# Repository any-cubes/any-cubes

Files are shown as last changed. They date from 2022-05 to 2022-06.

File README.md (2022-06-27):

# Any-Cubes

_Didactic toy for machine teaching and IoT_  

teaser (https://vimeo.com/488949042)

Any-Cubes is a prototype didactic toy for schools and maker spaces, with which children can intuitively and playfully explore and understand machine learning as well as Internet of Things technology. Our prototype is a combination of deep learning-based image classification and machine-to-machine (m2m) communication via [MQTT](https://mqtt.org/). The system consists of three physical and tangible cubes.

Cube 1 («[Vision-Cube](cubes/vision-cube/README.md)») is a modification of [Google Coral’s Teachable Machine](https://coral.ai/projects/teachable-machine/) and can be trained to recognize objects or scenes.
The machine learning functionality is running directly on the Raspberry Pi board, accelerated using a Google Edge TPU Stick.

Via the MQTT protocol, the Vision-Cube broadcasts its detected class ("1", "2" or "3") to other Any-Cubes devices ("Light-Cube" and "Maker-Cube").

Cube 2 («[Light-Cube](cubes/light-cube/README.md)») visualises the detected class of the Vision-Cube by changing the color of its LEDs.

Cube 3 («[Maker-Cube](cubes/maker-cube/README.md)») can be used to control other circuits using relays. It can for example be used to open an electronic cat door, whenever the Vision-Cube detects a cat.

It addition to the physical cubes, apps using web-technologies can be created easily to react to the changes of the Vision-Cube.
One such app is «[Shapes](apps/shapes-app/README.md)» – it shows different graphical shapes to visualise the classes being detected by the Vision-Cube. It can be used as a boilerplate to create custom apps that react to the Vision-Cube.

# Publications
 
Scheidt, A., & Pulver, T. (2019). Any-Cubes: A Children’s Toy for Learning AI: Enhanced Play with Deep Learning and MQTT. Proceedings of Mensch Und Computer 2019. [https://doi.org/10.1145/3340764.3345375](doi.org/10.1145/3340764.3345375)

# Contributors

Any-Cubes is a project by [Alexander Scheidt](https://www.fh-potsdam.de/studium-lehre/projekte/any-cubes) and [Tim Pulver](https://timpulver.de/) with contributions by [Meliani Meliani](https://www.linkedin.com/in/meliani-meliani-7a856b1a4/?originalSubdomain=de) (research and organisation of workshops), [Lukas Schmidt Wiegand](https://www.linkedin.com/in/lukas-schmidt-wiegand-67b990172/) (industrial design) and [Sabina Fimbres Sabugal](https://www.linkedin.com/in/sabina-fimbres-sabugal-7a253a213/) (graphic design for posters).

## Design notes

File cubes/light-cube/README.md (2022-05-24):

# Light-Cube

any-cubes-in-row

The Light-Cube (in the image above on the right) is part of the Any-Cubes family and can be used to visualise what the Vision-Cube (another cube from the Any-Cubes family) detects.

It listens to a special MQTT message from the Vision-Cube.

## Why Is This Useful?

The Light-Cube can be used in two ways:

1. As a helper to train the Vision-Cube – it shows which class the Vision-Cube currently sees and therefore makes training easier
2. As an alarm device – you can set up the Vision-Cube in one room, and the Light-Cube in another. When the Vision-Cube sees something that you trained it on, the light of the Light-Cube will change accordingly.

## Folder Contents

- [3D](3d/README.md): 3D-printable files to print the Light-Cube case, connection-rims and base plate
- [Code](code/README.md): The Arduino code
- [Wiring](wiring/README.md): Explains how to connect the electronic parts

## Required Electronic Parts

- **Arduino Nano 33 IoT**
  - [docs.arduino.cc/hardware/nano-33-iot](https://docs.arduino.cc/hardware/nano-33-iot)
- **LED Matrix**
  - [Adafruit NeoPixel Matrix 8x8](https://www.adafruit.com/product/1487) (or compatible LED matrix)
- **Logic Level Converter**
  - [SN74AHCT125N](https://eu.mouser.com/ProductDetail/Texas-Instruments/SN74AHCT125N?qs=1wQRf3HkBjyxwrHMwAiMfw%3D%3D) – we recommend this one, as most normal logic level converters don’t work well with NeoPixels
- **USB Powerbank**
  - Only needed if you want to carry the Light-Cube around
  - Make sure it delivers enough Ampere
  - We use Ansmann USB Powerbank 5.4: 5V, 2.4 Ampera max: https://www.ansmann.de/consumer/powerbanks/powerbank-54
  - Some powerbanks have a *clever* automation to automatically power off when the connected device is disconnected. With microcontroller-boards this can result in the power bank shutting off randomly, even when the board is still connected (because it might draw only very little power). The powerbank we are using didn’t do that, but some others that we tried did.
- **USB cable**
  - Make sure to use a quality cable, especially super thin ones might not work

## Getting Started

1. Connect the board and LED matrix as described in [wiring](wiring/README.md)
2. Train the Vision-Cube
3. The Light-Cube will update its color according to the detected class of the Vision-Cube

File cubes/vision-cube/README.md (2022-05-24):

# Vision-Cube

Vision-Cube being used to recognize a giraffe

The Vision-Cube uses machine learning to recognize different objects and scenes (in the image above, to recognize a giraffe). It can be trained using just a few images.
The Vison-Cube is based on [Google Coral’s Project Teachable](https://coral.ai/projects/teachable-machine/).

## Hardware

- Raspberry Pi 3 B+
- Google Coral USB Accelerator
- 5V USB Powerbank (with 2.5A or more)
- Four buttons (three for classification, one to reset the model)

## Software

We use a modified version of the [Google Coral’s Teachable Machine](https://github.com/google-coral/project-teachable) project.

Our modifications include:

- Installed an MQTT server ([mosquitto](https://mosquitto.org/)) to the Raspberry Pi
- Added auto-start of the detection script, so it starts automatically when the Raspberry Pi starts (see [Sparkfun – How to Run a Raspberry Pi Program on Startup](https://learn.sparkfun.com/tutorials/how-to-run-a-raspberry-pi-program-on-startup/all))

We might provide an SD-card image of the Vision-Cube on request that contains all modifications.

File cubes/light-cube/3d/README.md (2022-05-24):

# Light-Cube 3D Files

You can choose between different formats:

- Fusion 360
- OBJ
- STEP
- STL (contains some exclusive parts)

If you choose Fusion 360, OBJ or STEP, please also have a look at the STL folder. It might contain some parts than are not included in the other folders.

The base-plate is a work-in-progress and contains some holes, which are planned to be used in a later version of the Light-Cube (for example to contain a power-on/off switch and a USB charging port). Feel free to create your own base plate that fits to the base cube without these holes.

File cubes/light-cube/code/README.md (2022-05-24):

# Light-Cube Code

Here you can find the Arduino code for the Light-Cube.

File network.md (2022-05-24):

# Network

Any-Cubes modules need two things to communicate:

1. A network that it can connect to
2. An MQTT server (runs on the Vision-Cube)

## Local Usage

Any-Cubes currently only communicate locally, they don’t depend on an internet connection being available.

If you have a spare router, you can use it for the Any-Cubes network. This way it is easy to take Any-Cubes to a new location and start them up, without the need to re-configure their WiFi settings.

With an Any-Cubes specific router, the workflow would be like this:

1. Plug in the router. Wait a minute until it is ready.
2. Power up the Vision-Cube. Wait a minute until it is booted up and the MQTT server is ready.
3. Power up the remaining cubes

Using a separate network / router for the Any-Cubes is more secure, because all communication is separate to your regular WiFi network. Everything stays local, so there is no chance that your devices are exposed to the internet (which would require further work to secure the devices).

If you want to use any of the Any-Cubes apps on a tablet device you also need to do the following:

1. Connect the tablet to the same network the Any-Cubes are connected to
2. Serve the `index.html` file of the app, for example using the app [Kiosk Pro](https://www.kioskgroup.com/pages/kiosk-pro-software)

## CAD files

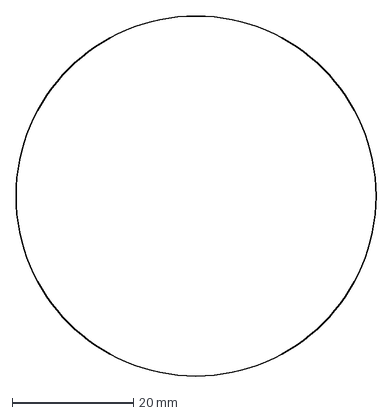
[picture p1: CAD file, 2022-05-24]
cubes/light-cube/3d/DXF-diffusor-for-laser-cutting/diffusor.dxf
59.5 x 59.5 mm

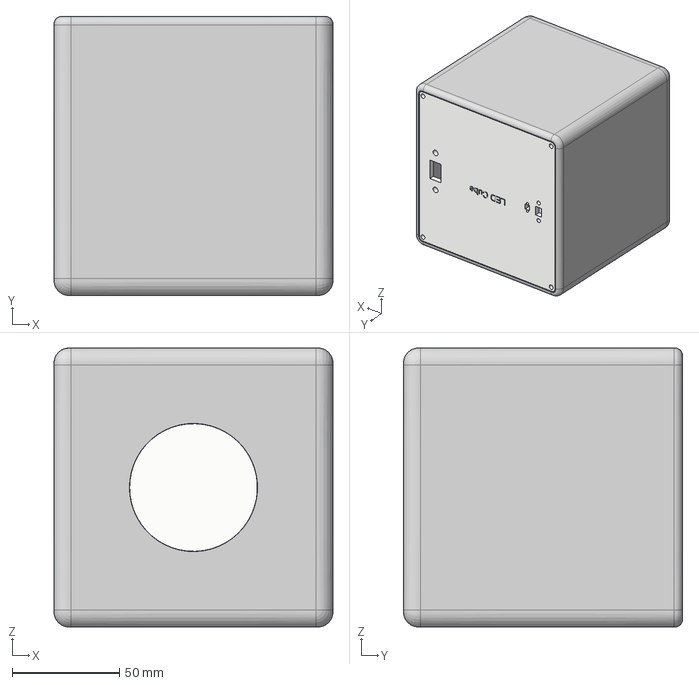
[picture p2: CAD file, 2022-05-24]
cubes/light-cube/3d/step/light-cube.step
130.0 x 130.0 x 130.0 mm

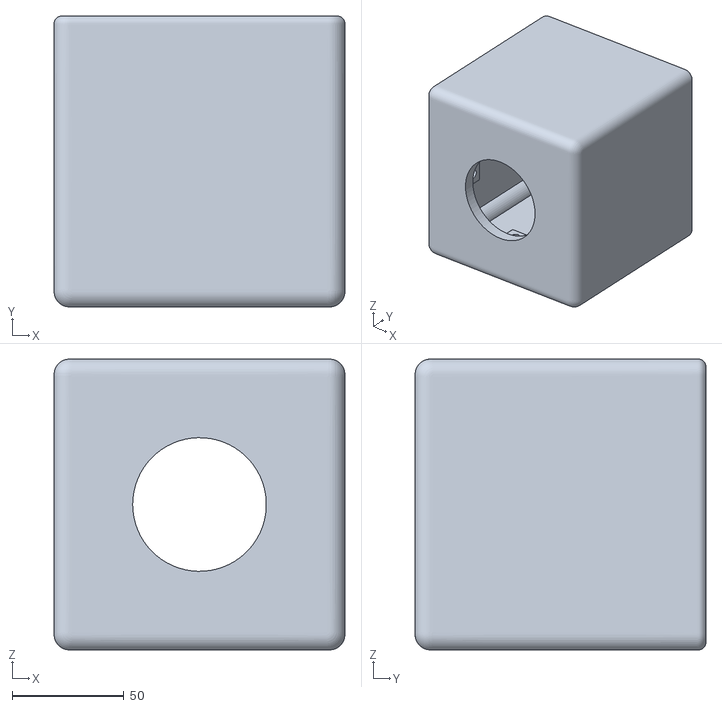
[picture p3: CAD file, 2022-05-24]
cubes/light-cube/3d/stl/light-cube-cube.stl
130.0 x 130.0 x 130.0

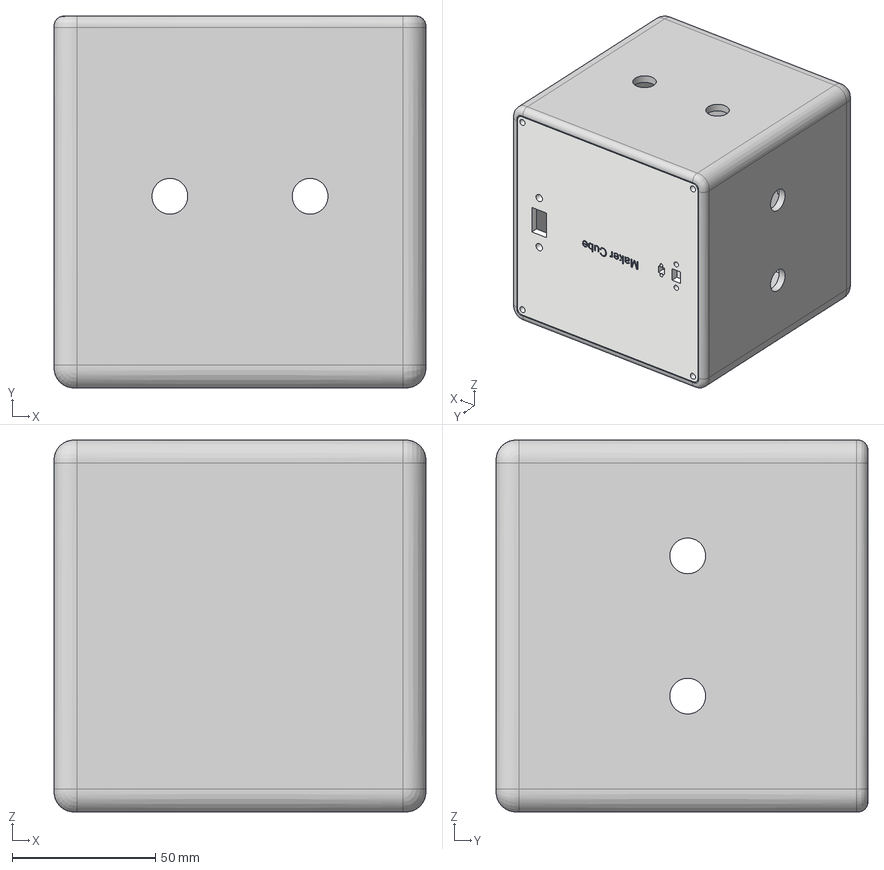
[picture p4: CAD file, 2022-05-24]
cubes/maker-cube/3d/step/maker-cube.step
130.0 x 130.0 x 130.0 mm

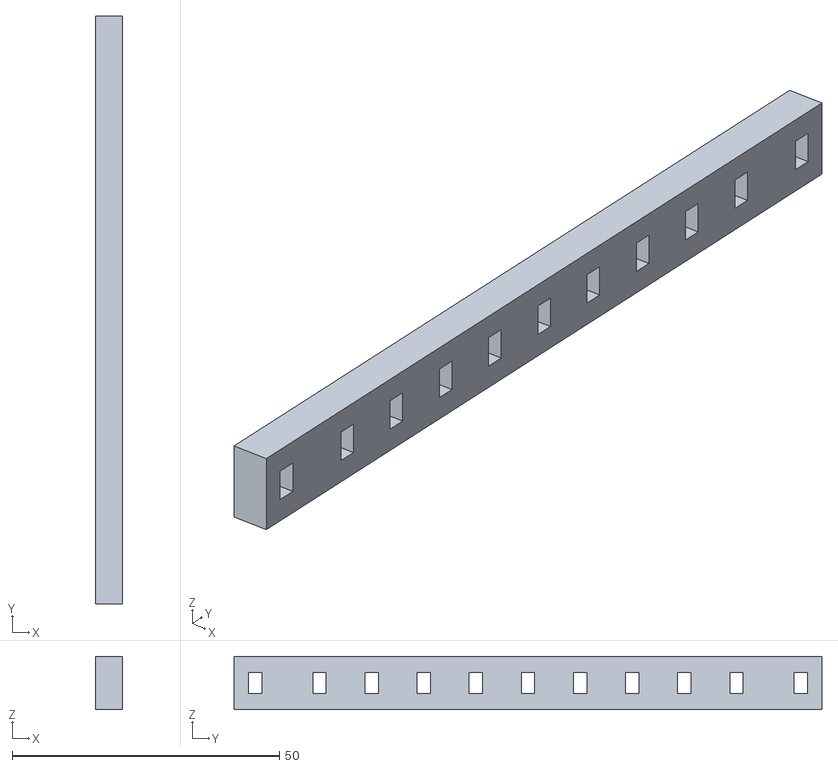
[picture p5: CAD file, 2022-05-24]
cubes/maker-cube/3d/stl/maker-cube-truss-bridge-vertical.stl
5.00 x 110.0 x 10.0

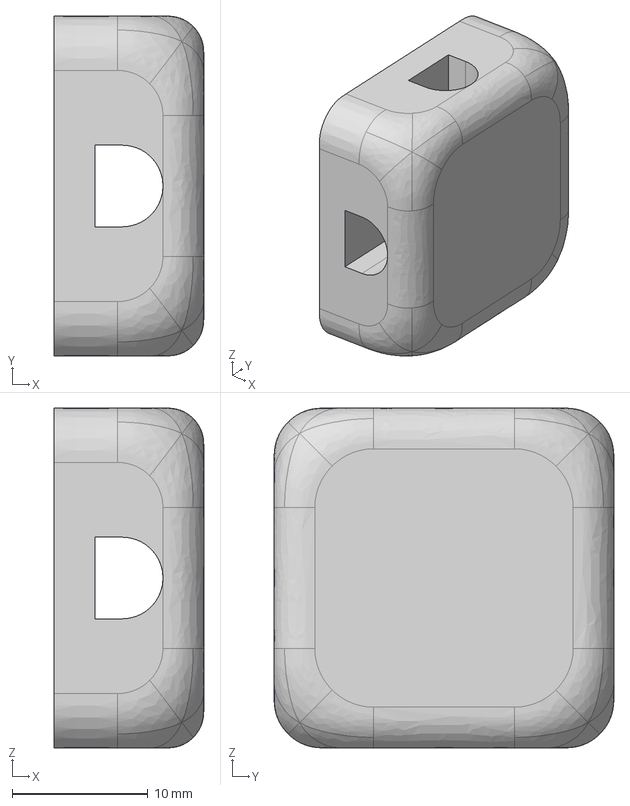
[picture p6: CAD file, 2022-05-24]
cubes/light-cube/3d/step/light-cube-mounting-pad.step
11.0 x 25.0 x 25.0 mm

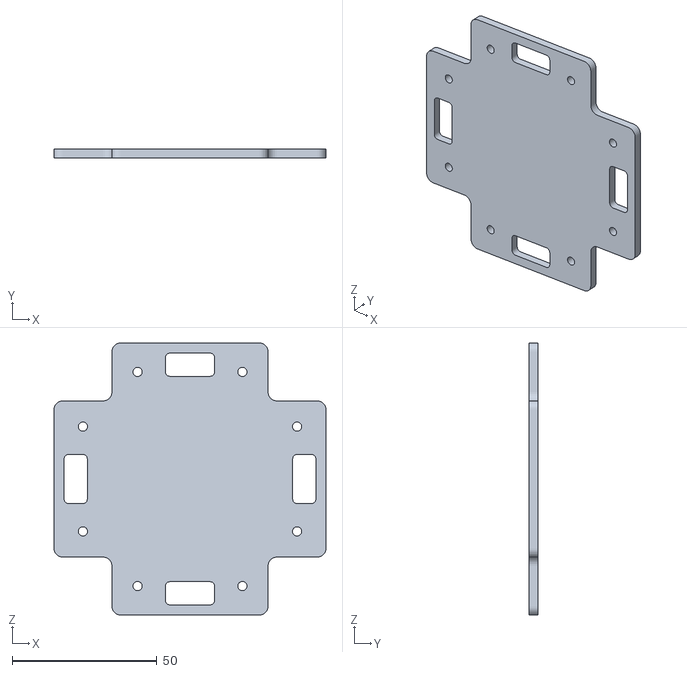
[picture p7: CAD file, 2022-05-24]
cubes/light-cube/3d/stl/light-cube-led-holder.stl
94.0 x 3.00 x 94.0

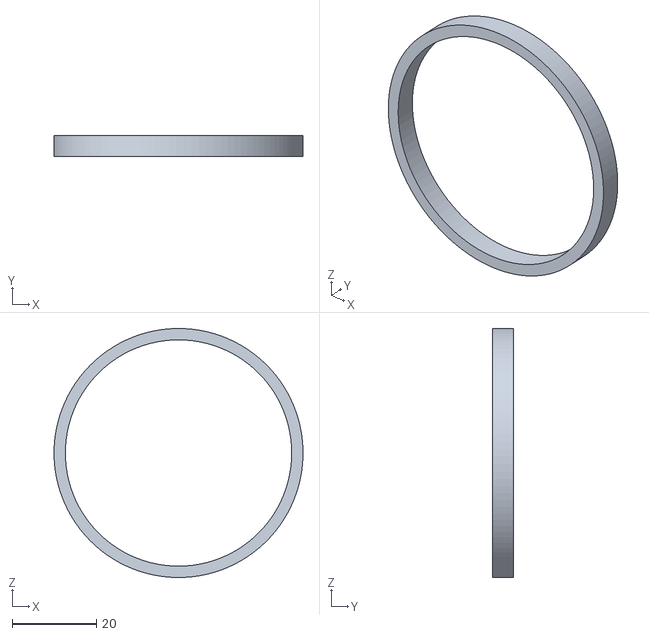
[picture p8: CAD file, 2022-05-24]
cubes/light-cube/3d/stl/light-cube-ring.stl
59.1 x 5.00 x 59.1

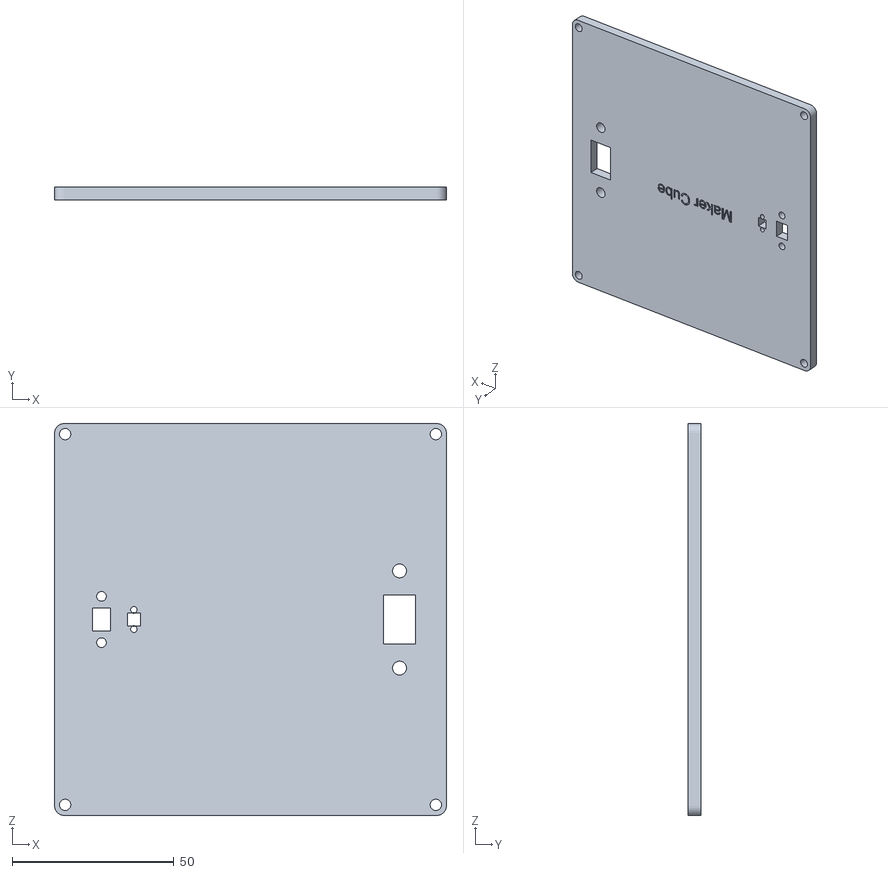
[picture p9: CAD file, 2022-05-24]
cubes/maker-cube/3d/stl/maker-cube-ground-plate.stl
121.0 x 4.00 x 121.0

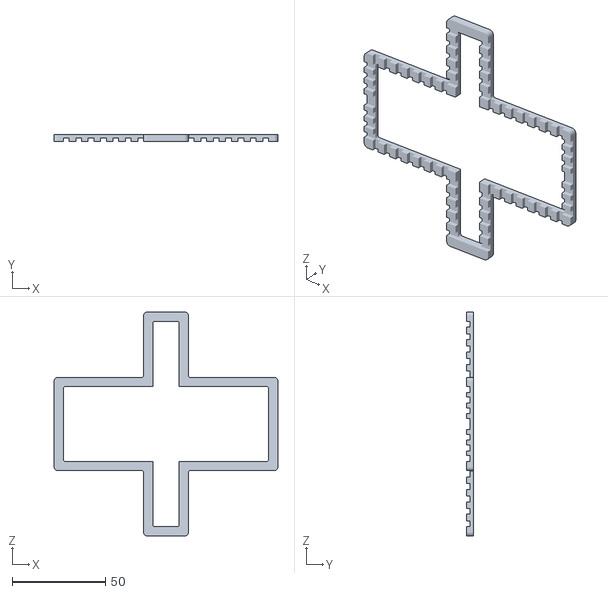
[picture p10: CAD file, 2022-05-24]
cubes/maker-cube/3d/stl/maker-cube-truss-cross-top.stl
120.0 x 4.00 x 120.0

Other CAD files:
cubes/maker-cube/3d/stl/maker-cube-cube.stl
cubes/light-cube/3d/stl/light-cube-ground-plate.stl
cubes/maker-cube/3d/stl/maker-cube-truss-cross-bottom.stl
cubes/light-cube/3d/fusion360/light-cube-mounting-Pad.f3d
cubes/light-cube/3d/fusion360/light-cube.f3d
cubes/light-cube/3d/stl/light-cube-mounting-pad.stl
cubes/maker-cube/3d/fusion360/maker-cube-mounting-pad.f3d
cubes/maker-cube/3d/fusion360/maker-cube.f3d
cubes/maker-cube/3d/stl/maker-cube-mounting-pad.stl

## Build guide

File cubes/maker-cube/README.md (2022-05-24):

# Maker-Cube

Maker-Cube with Vision Cube and Cow

The Maker-Cube is part of the Any-Cubes family and can be used to turn up to four external circuits on or off. Internally it uses relays, which either open or close another connected circuit. In the image above, it is being used to turn on a windmill toy whenever the Vision-Cube detects a cow.

It listens to a special MQTT message from the Vision-Cube (another cube from the Any-Cubes family that uses a camera and machine learning to recognise different scenes, so called «classes»).

## Why Is This Useful?

Let’s say you trained the Vison-Cube to recognise your cat and you also built a custom cat door that can electronically be opened or closed. You could use the Maker-Cube to connect the two projects, so whenever the Vision-Cube detects the cat, the cat door automatically opens.

## Folder Contents

In this repository you will find the following sub-folders:

- [3D](3d/README.md): 3D-printable files to print the Maker-Cube case, connection-rims and base plate
- [Code](code/README.md): The Arduino code
- [Wiring](wiring/README.md): Explains how to connect the electronic parts

## How Can a Circuit Be Connected to the Maker-Cube?

The Maker-Cube can be used to control any other (low-power) circuit, for example one of your Arduino projects or an electronic toy running on batteries, with minimal modifications.

To connect the Maker-Cube to other circuits, banana cables are being used.

**Attention:** While connecting high power circuits (e.g. a coffee machine) to the Maker-Cube might work, we do not recommend it, because it is very dangerous. Only use the Maker-Cube to control low-power devices / circuits, for example battery-driven projects.

To control another circuit using the Maker-Cube, you need to cut its power line. For an Arduino project this might be its VCC / 3.3V / 5V line.

One side of the cable then goes into one of the two ports of a Maker-Cube’s side, the other side of the cable goes into the other port. Whenever this side of the Maker-Cube is activated (via the Vision-Cube), the connection between the two ports is closed, and therefore the circuit of the connected project is closed as well.

**Please note:** The connected circuit must have its own power source. The Maker-Cube simply closes the circuit, but it does not provide power.

## Required Electronic Parts

- **NodeMCU V2**
  - We use a similar version to this one: https://joy-it.net/de/products/SBC-NodeMCU
- **Logic Level Converter**
  - We use 4-channel I2C-safe Bi-directional Logic Level Converter - BSS138: https://www.adafruit.com/product/757
- **Relais**
  - We use a Velleman 4x Relay VMA400: https://www.velleman.eu/products/view/?id=435558
  - Other relays might or might not work with a 3.3V development board. We tried a few other ones that only worked with 5V development boards.
- **Banana jacks / connector cables**
  - There are a multitude of banana jacks / connector cables. The most important thing is that the plug fits to the connector
  - For example: https://uk.farnell.com/hirschmann-testmeasurement/972354102/socket-4mm-safety-blue-mvl-s/dp/1011403
  - Search for «banana jack surface mount» to find others
  - For the Vision-Cube you need 2 jacks for each side, so 8 in total
  - You need one (long) banana cable per project that you want to connect
- **USB Powerbank**
  - Only needed if you want to carry the Maker-Cube around
  - Make sure it delivers enough Ampere
  - We use Ansmann USB Powerbank 5.4: 5V, 2.4 Ampera max: https://www.ansmann.de/consumer/powerbanks/powerbank-54
  - Some powerbanks have a *clever* automation to automatically power off when the connected device is disconnected. With microcontroller-boards this can result in the power bank shutting off randomly, even when the board is still connected (because it might draw only very little power). The powerbank we are using didn’t do that, but some others that we tried did.
- **USB cable**
  - Make sure to use a quality cable, especially super thin ones might not work

## Getting Started

1. Connect the board, relay and banana jacks as described in [wiring](wiring/README.md)

2. Cut the banana cable in half

3. Solder on one end of the banana cable to the end of the cable that opens the circuit of your other project
4. Do the same with the other half / side of the cable

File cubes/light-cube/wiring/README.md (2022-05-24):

# Light-Cube Wiring

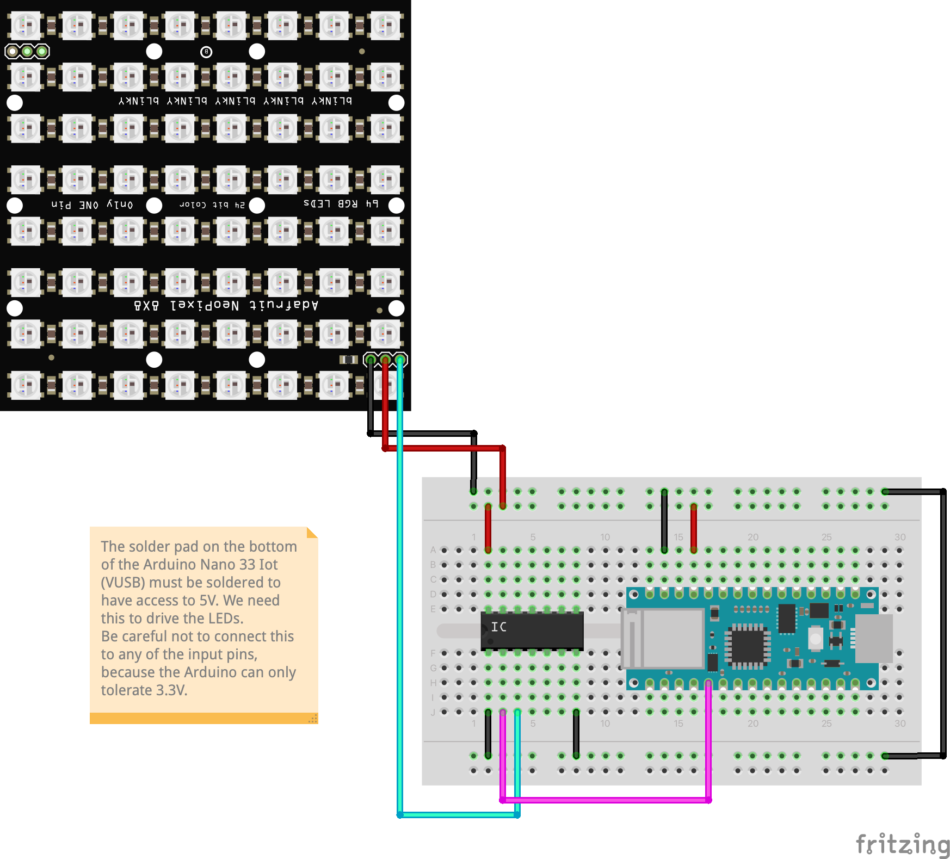
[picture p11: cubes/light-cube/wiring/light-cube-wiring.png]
Light-Cube Wiring


## Fritzing Installation

If looking at the wiring image (light-cube-wiring.png) is not enough and you want too view / edit the Fritzing file, you need to follow a few steps first:

1. Install [Fritzing](https://fritzing.org/)
2. Download the part *Adafruit NeoPixel NeoMatrix 8x8.fzpz* from [GitHub](https://github.com/adafruit/Fritzing-Library/blob/master/parts/Adafruit%20NeoPixel%20NeoMatrix%208x8.fzpz)
3. Downlod the part *NodeMCU v1.0* from [GitHub](https://github.com/squix78/esp8266-fritzing-parts/blob/master/nodemcu-v1.0/NodeMCUV1.0.fzpz)
4. Double click both files to open them in Fritzing
5. Open the Light-Cube Fritzing file

Please note: There is no Fritzing part for the *SN74AHCT125N logic level converter*, we just use an IC here with the same number of pins. The orientation of the part is so that its text can be read.

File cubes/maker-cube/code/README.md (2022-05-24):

# Maker-Cube Code

Here you can find the Arduino code for the Maker-Cube.

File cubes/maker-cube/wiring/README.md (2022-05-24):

# Maker-Cube Wiring

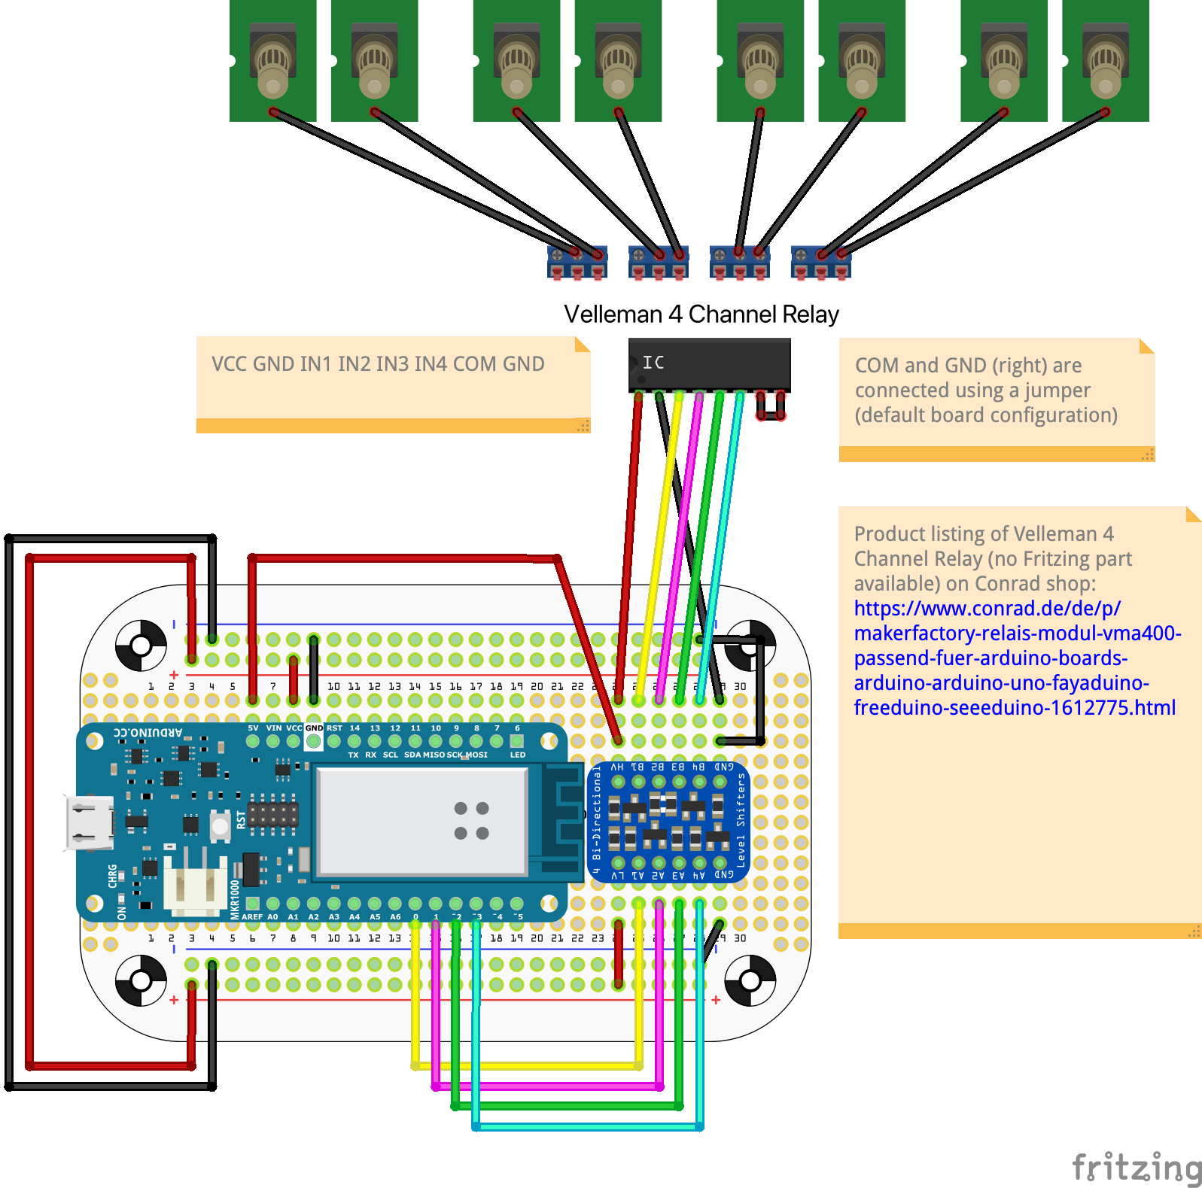
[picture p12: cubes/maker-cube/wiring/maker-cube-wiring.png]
Maker-Cube Wiring


## Fritzing Diagram

To view / edit the Fritzing file (for better resolution), you need to perform a few steps first:

1. Install [Fritzing](https://fritzing.org/)
2. Download the part *Adafruit PermaProto Mint Tin Size Breadboard* from [GitHub](https://github.com/adafruit/Fritzing-Library/blob/master/parts/Adafruit%20PermaProto%20Mint%20Tin%20Size%20Breadboard.fzpz)
3. Double click it to open it in Fritzing
4. Open the Maker-Cube Fritzing file

## Velleman VMA400 Board

The design does not contain the used relay board ([Velleman VMA400](https://www.velleman.eu/products/view/?id=435558)), but the Fritzing file uses the same port layout as this board, so you will be able to translate the design 1 to 1 to the board.

The IC symbolizes the Velleman VMA400 ports to the Arduino, the top part shows how to connect the outputs of the Velleman VMA400 board to the banana jacks.

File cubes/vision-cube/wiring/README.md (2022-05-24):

# Vision-Cube Wiring

To control the Vision-Cube, four buttons (including resistors) need to be connected to the Raspberry Pi.

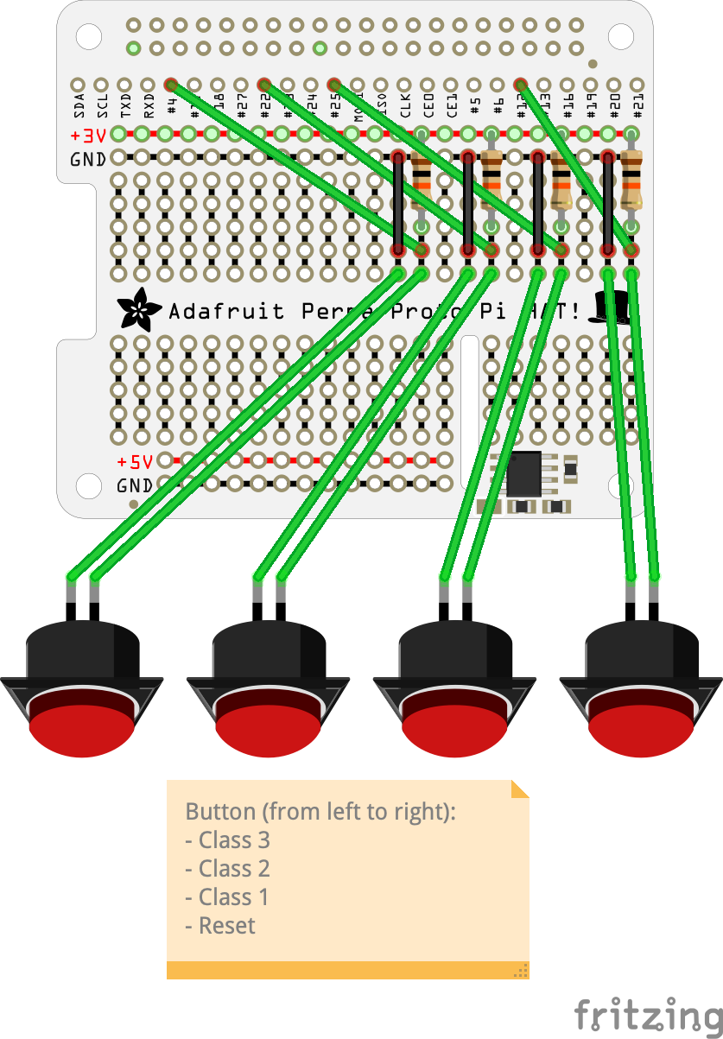
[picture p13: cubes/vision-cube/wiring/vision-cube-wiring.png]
Vision-Cube Wiring


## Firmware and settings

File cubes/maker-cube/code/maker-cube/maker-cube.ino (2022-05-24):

/*
 * Firmware for Any-Cubes Maker-Cube
 * ---------------------------------
 * The Maker-Cube is an output device from the Any-Cubes family.
 * Via its relays, it can be used to control up to four external (low-power) circuits
 * by switching the relays on or off individually.
 * It listens to control signals via MQTT from the Vision-Cube.
 * 
 * Author: The Any-Cubes authors
 * License: MIT
 * 
 * Hardware:
 * - NodeMCU V2:
 *     - We use a similar version to this one: https://joy-it.net/de/products/SBC-NodeMCU
 * - 4x Logic Level Converter:
 *     - We use a 4-channel I2C-safe Bi-directional Logic Level Converter - BSS138: https://www.adafruit.com/product/757
 * - 4x Relay
 *     - We use a Velleman VMA400: https://www.velleman.eu/products/view/?id=435558
 * - USB Powerbank:
 *     - Make sure it delivers enough Ampere
 *     - We use Ansmann USB Powerbank 5.4: 5V, 2.4 Ampera max: https://www.ansmann.de/consumer/powerbanks/powerbank-54
 * 
 * Libraries:
 * - PubSubClient (install via Arduino Library Manager)
 * - EspMQTTClient (install via Arduino Library Manager)
 * 
 * If you don’t find the specific version of the NodeMCU you are using in the Arduino menu,
 * try using NodeMCU 1.0 (works with the joy-it.net NodeMCU board).
 */

#include "EspMQTTClient.h"

/**
 * For the import below to work, duplicate the file "credentials_example.h",
 * rename it to "credentials.h" and specify your credentials.
 */
#include "credentials.h"

const int RELAY_PIN_1 = D0;
const int RELAY_PIN_2 = D1;
const int RELAY_PIN_3 = D2;
const int RELAY_PIN_4 = D3;

unsigned long PING_INTERVAL = 5000;

unsigned long lastPingMillis = 0;
int previousActiveRelay = 0;
int activeRelay = 0;

EspMQTTClient client(
  ssid,
  password,
  mqttServer,
  mqttUsername,
  mqttPassword,
  "maker-cube", // MQTT client name
  1883 // MQTT port
);

void setup() {
  Serial.begin(115200);

  pinMode(RELAY_PIN_1, OUTPUT);
  pinMode(RELAY_PIN_2, OUTPUT);
  pinMode(RELAY_PIN_3, OUTPUT);
  pinMode(RELAY_PIN_4, OUTPUT);

  digitalWrite(RELAY_PIN_1, LOW); 
  digitalWrite(RELAY_PIN_2, LOW);
  digitalWrite(RELAY_PIN_3, LOW);
  digitalWrite(RELAY_PIN_4, LOW);

  client.enableDebuggingMessages(); // Enable debug log via serial
  // Once the device is disconnected / loses power, send a "0" as
  // status to let other cubes know that it is offline.
  client.enableLastWillMessage("/any-cubes/maker-cube/status", "0");
}

// Called once Wifi and MQTT are connected
void onConnectionEstablished() {
  // Subscribe to class changes from the Vision-Cube
  client.subscribe("/any-cubes/visio-cube/active-class", [](const String & payload) {
    Serial.print("Vison-Cube: class changed: "); Serial.println(payload);
    // The payload is expected to be a number that represents the currently active class,
    // either 1, 2, 3 or 4.
    // This variable stands for one of the four relays and means that this relay will be closed,
    // while the other 3 relays will be open.
    activeRelay = payload.toInt();
  });
  // Send a message to let other Cubes know that this device is online
  client.publish("/any-cubes/maker-cube/status", "1");
}

void loop() {
  unsigned long curMillis = millis();
  client.loop();

  // Check if the activeRelay variable changed since last loop,
  // if it did, update the relays, so that only the one with the
  // active class is closed.
  if (activeRelay != previousActiveRelay) {
    digitalWrite(RELAY_PIN_1, activeRelay == 1 ? HIGH: LOW);
    digitalWrite(RELAY_PIN_2, activeRelay == 2 ? HIGH: LOW);
    digitalWrite(RELAY_PIN_3, activeRelay == 3 ? HIGH: LOW);
    digitalWrite(RELAY_PIN_4, activeRelay == 4 ? HIGH: LOW);
    previousActiveRelay = activeRelay;
  }

  // Every now and then send a message to the MQTT server to
  // let other cubes know this device is still working
  if (curMillis > lastPingMillis + PING_INTERVAL) {
    client.publish("/any-cubes/maker-cube/status/ping", "alive");
    lastPingMillis = curMillis;
  }
}

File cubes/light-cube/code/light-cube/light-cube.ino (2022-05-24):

 /*
 * Firmware for Any-Cubes Light-Cube
 * ---------------------------------
 * The Light-Cube is an output device from the Any-Cubes family.
 * It lights up in one of three colors to visualise what the Vision-Cube (another
 * cube from the Any-Cubes family) sees.
 * It listens to control signals via MQTT from the Vision-Cube.
 * 
 * Author: The Any-Cubes team
 * 
 * Hardware:
 * - Arduino Nano 33 IoT
 * - Adafruit NeoPixel NeoMatrix 8x8 RGB LED Matrix
 * - SN74AHCT125N logic level converter
 * 
 * Libraries:
 * - WiFiNINA
 * - PubSubClient
 * - Adafruit NeoMatrix
 */ 

#include <Adafruit_NeoMatrix.h>
#include <WiFiNINA.h> 
#include <PubSubClient.h>

/**
 * For the import below to work, duplicate the file "credentials_example.h",
 * rename it to "credentials.h" and specify your credentials.
 */
#include "credentials.h"

#define LED_MATRIX_PIN 2

unsigned long PING_INTERVAL = 5000;

unsigned long lastPingMillis = 0;
int activeClass = 0;
int previousActiveClass = 0;

Adafruit_NeoMatrix matrix = Adafruit_NeoMatrix(8, 8, LED_MATRIX_PIN,
  NEO_MATRIX_TOP     + NEO_MATRIX_RIGHT +
  NEO_MATRIX_COLUMNS + NEO_MATRIX_PROGRESSIVE,
  NEO_GRB            + NEO_KHZ800);

const uint16_t colors[] = {
  matrix.Color(0, 0, 0),       // transparent (black)
  matrix.Color(0, 0, 255),     // blue
  matrix.Color(255, 114, 119), // pink
  matrix.Color(0, 255, 0)      // green
};

/*
 * Color - Vision-Cube active class mapping:
 * --------------------------------------------
 * Transparent:  0 (no class)
 * Blue:         class 1
 * Pink:         class 2
 * Green:        class 3
 */

char subTopic[] = "/any-cubes/visio-cube/active-class";

WiFiClient wifiClient;
PubSubClient client(wifiClient);

void setupMatrix() {
  matrix.begin();
  matrix.setBrightness(100);
  matrix.fillScreen(colors[0]);
  matrix.show();  
}

void setupWifi()  {
  delay(10);

  Serial.println("");
  Serial.print("Trying to connect to ");
  Serial.println(ssid);
  WiFi.begin(ssid, password);

  while (WiFi.status() != WL_CONNECTED) {
    delay(500);
    Serial.print(".");
  }

  randomSeed(micros());

  Serial.println("");
  Serial.println("WiFi connected.");
  Serial.print("Assigned IP address: ");
  Serial.println(WiFi.localIP());
}

void callback(char* topic, byte* payload, unsigned int length) {
  Serial.print("MQTT Message received [");
  Serial.print(topic);
  Serial.print("] ");
  String s = String((char*)payload);
  Serial.println(s);

  // We assume that the payload is a number (representing the class detected by the Vision-Cube)
  activeClass = s.toInt();
  Serial.print("Active class: "); Serial.println(activeClass);

  // If the active class is outside the expected range [0..3], we correct it:
  if (activeClass < 0) {
    activeClass = 0;
  }
  else if (activeClass > 3) {
    activeClass = 0;
  }
}

void reconnectMqtt() {
  while (!client.connected()) {
    Serial.print("Attempting MQTT connection...");

    if (client.connect("light-cube", mqttUsername, mqttPassword)) {
      Serial.println("Connected to MQTT server.");
      client.subscribe(subTopic);
    } else {
      Serial.print("MQTT connection failed! client state: ");
      Serial.print(client.state());
      Serial.println("See https://pubsubclient.knolleary.net/api#state for client state descriptions.");
      Serial.println("Will try again in 5 seconds ...");
      delay(5000);
    }
  }
}

void setup() {
  Serial.begin(115200);
  setupMatrix();
  setupWifi();
  client.setServer(mqttServer, 1883);
  client.setCallback(callback);
}

void loop() {
  if (!client.connected()) {
    reconnectMqtt();
  }
  client.loop();

  unsigned long curMillis = millis();

  if (previousActiveClass != activeClass) {
    matrix.fillScreen(colors[activeClass]);
    matrix.show();
    previousActiveClass = activeClass;
  }
  
  if (curMillis > lastPingMillis + PING_INTERVAL) {
    client.publish("/any-cubes/light-cube/status/ping", "alive");
    lastPingMillis = curMillis;
  }
}
